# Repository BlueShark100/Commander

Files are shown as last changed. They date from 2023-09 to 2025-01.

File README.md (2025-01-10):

# Commander (code name Sirius 02)

Commander is essentially a little programable toy you can bring around to practice coding and have fun with if you not home with your usual projects. It's main purpose and code provides a menu that allows you to navigate through different OS tips and tricks along with keyboard shortcuts and their descriptions. Its like a little helper to make you a pro at navigating your computer faster and easier. I'm writing the code so respective to MacOS commands but feel free to interpret your own commands and edit the lists within the code to make your own version of the Commander. You can go as far as writing your own code for the board too! I'll provide pin assignments on an example code for pong on the project (after I finish the primary code). 

This project includes a builtin D-Pad, a 128*64 OLED display on an I2C connection, EEPROM with 4Kbytes, and side-fireing WS2812B LEDs to light up the case!

# Current status of the project (Second Version didnt work, Ordering test PCB)

### The Quick Version

- Completed reference animations
- Coding menu animation (Running into memory limits)
- **Test Board Arrived (Debugged one Issue! more to fix)**
- Case is hard to take apart

### Code

This is currently in development. I'm working to complete V1 still and if you happen to come across this repo feel free to help out. Right now I'm working on getting the menu animation completed on the display by using lists with coordinates for each element. As it goes through the loop it will "animate" the menu into creation. **Working on a solution to avoid overflowing the display buffer which may be the cause of unexpected behavior when running the animations.** Defined the animations as separate functions to avoid clutter at the top of the program where the primary functional code is.

Navigation through different folders and information is almost complete.

### Board

Originally I was planning on using the ATmega16U2 however I kept running into issues trying to find custom firmware to have it work as the primary MCU on the board. This MCU is commonly found on the Arduino Uno used as a USB to serial converter. I found a github repo called HoodLoader that aims to use this MCU as a microcontroller along side the primary MCU of the board (ATmega328p) however I honestly could never figure out how to get it to work with a standalone ATmega16U2. If anyone knows how to get the ATmega16U2 to run as a standalone MCU that would be the primary goal since that would allow for USB HID support

The new board will be using the CH340 USB to serial converter (using the RedBoard Qwuicc schematic for guidance since the data sheet is all in Chinese) and the ATmega328p. There will be no USB HID support but you should be able to program the board directly from a USB and the Arduino IDE. I'm adding an EEPROM module to store some of the byte arrays so that it doesn't take up program memory space. The specific EEPROM would be the Microchip Tech AT24C32D-SSHM-T, its got 32Kbits of storage (4Kbytes) and uses and I2C communication. The second version of the board includes output pins for the currently unused Arduino pins for expandability and a solder jumper for the Write Protect configuration on the EEPROM module.

Aside from the new board design (V2) there is a test board (V3) for me to try and debug problems with the circuit. I tried replicating the circuit from my schematic on a breadboard and it worked fine. However the circuit on the board itself seems to have a flaw that prevents me from flashing the bootloader onto the ATmega238p on the board itself using another arduino. I'm hoping that the layout of the test board will better help me find whats going wrong and how i could fix it for what will hopefully be the final version. 

If you are an hardware engineer and know how to do this please reach out. Everything I know about designing PCBs and circuits has been primarily self taught so I would love to learn form an expert. 

### Casing

I'm printing the casing out of a sparkling black PLA from Microcenter (Brand: inland). This filament gives a great effect with the sparkles giving some extra interest to the surface without being too distracting. It also slightly transparent when printed thin enough which allows the LEDs to shine through and illuminates the components inside while looking super cool! 

Working on a better mechanism to connect the bottom plate securely while still being able to take it out easily. 

### Prototyping

I'm prototyping the project on a breadboard while I go. That way I can continue working on the code while I wait for a working board to arrive. This section is mainly to put some images of what it looks like so far. I also have the images so there something cool to look at instead of a bunch of text in the README file. 

Here's a test of what the LEDs within the Case might look like. This is using the first version of the PCB and none of the components are within the case. Hopes are that when I do have the LEDs working and the components are inside you can see a faint outline of the components within the case.

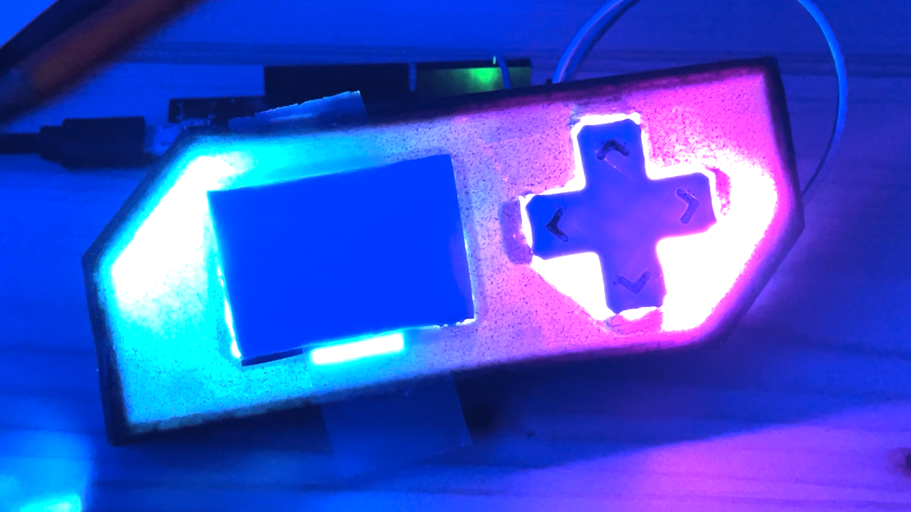
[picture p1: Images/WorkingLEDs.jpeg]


# How do I get one of my own?

**THIS PROJECT IS INCOMPLETE AT THE MOMENT. The code and files are not finalized and may not work as intended. Especially right now the project WILL NOT WORK.**

The commander project is a PCB at heart. You'll need to order the board from a manufacturer yourself. On top of the board you'll also have to order the components required for the circuit from lcsc. These components and the Gerber files for the PCB can be found under the PCB files. There will be a BOM that you can use to find the components quickly and easily in lcsc, the quantities will be defined for 1 board only but feel free to edit the quantities later if you want more boards or extra components.

Once the project is in working order I will write a guide for building this project from scratch.

# Extra tid bits

Heres the original sketch I drew when I first had the idea
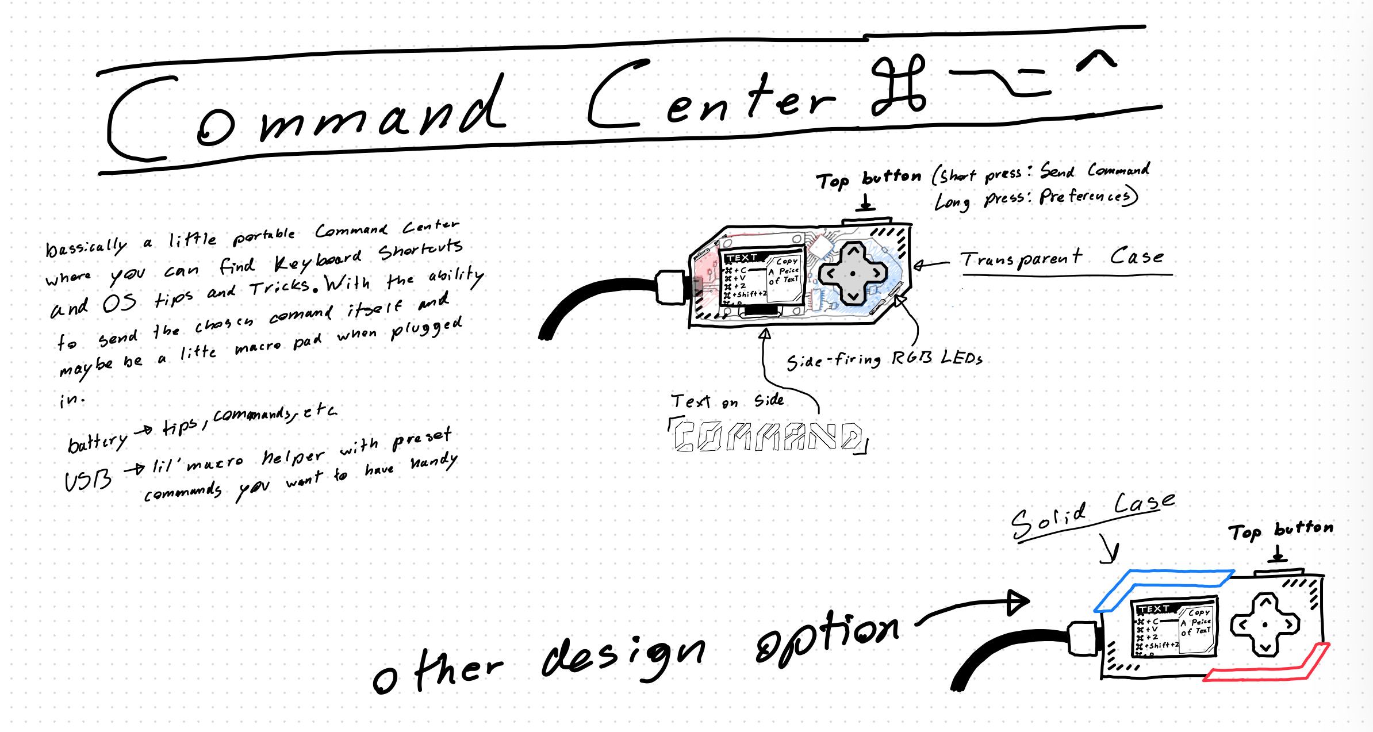
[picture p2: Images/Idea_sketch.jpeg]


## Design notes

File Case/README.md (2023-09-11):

# The Case
This case consists of two parts. The Case and the Case Bottom. The Case Bottom just 
squezes into the bottom of the case. Printed in sparkling black PLA from Microcenter

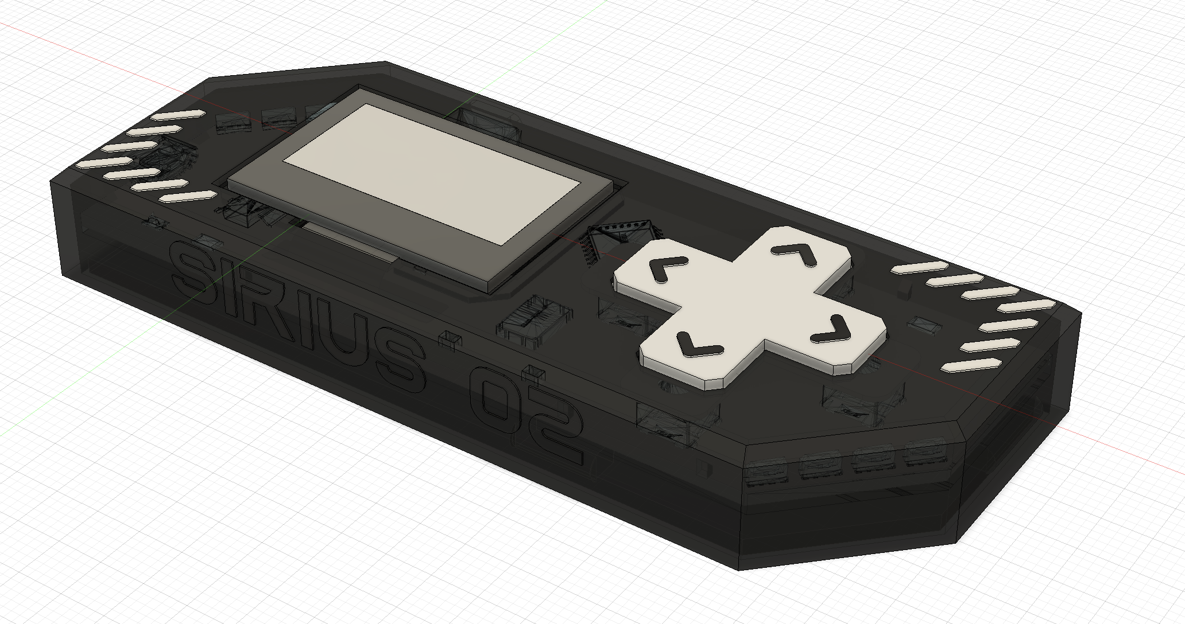
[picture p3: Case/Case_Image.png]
The case


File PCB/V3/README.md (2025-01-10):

# PCB V3

Version three is to try and debug the circuit used for V2. 

**Update!** I found an issue with the was I wired the 16MHz Crystal Oscilator I was using. I left the unused connections floating but I think I was suppost to ground them. I'm using a different one for now but I plan to make the original one work.

### issues

OLED Display is not working. Having trouble getting the CH340C to properly communicate with the MCU.

### Notes

- Sucsefully uploaded bootloater to MCU

- LEDs Working with MCU ✓

- Testing Button Reading soon

This PCB is designed for testing the circuit. There are lots of pads you can solder onto. *This one is mainly for me so I can see why the circuit for the last PCB didn't work.* I remade the circuit on a breadboard and it works so I'm real confused. I'll still include the same information as the last version that way it's known which component goes where and pin assignments for Arduino. The BOM is also the same as V2.

```
int Up_Button = 3;
int Down_Button = 4;
int Left_Button = 5;
int Right_Button = 6;
int LED_Data_Pin = 2;
//OLED(Address: 0x3C) and EEPROM(Waiting for board to arrive to confirm Address) are on the I2C bus on Pins A5(SCL) and A4(SDA)
```

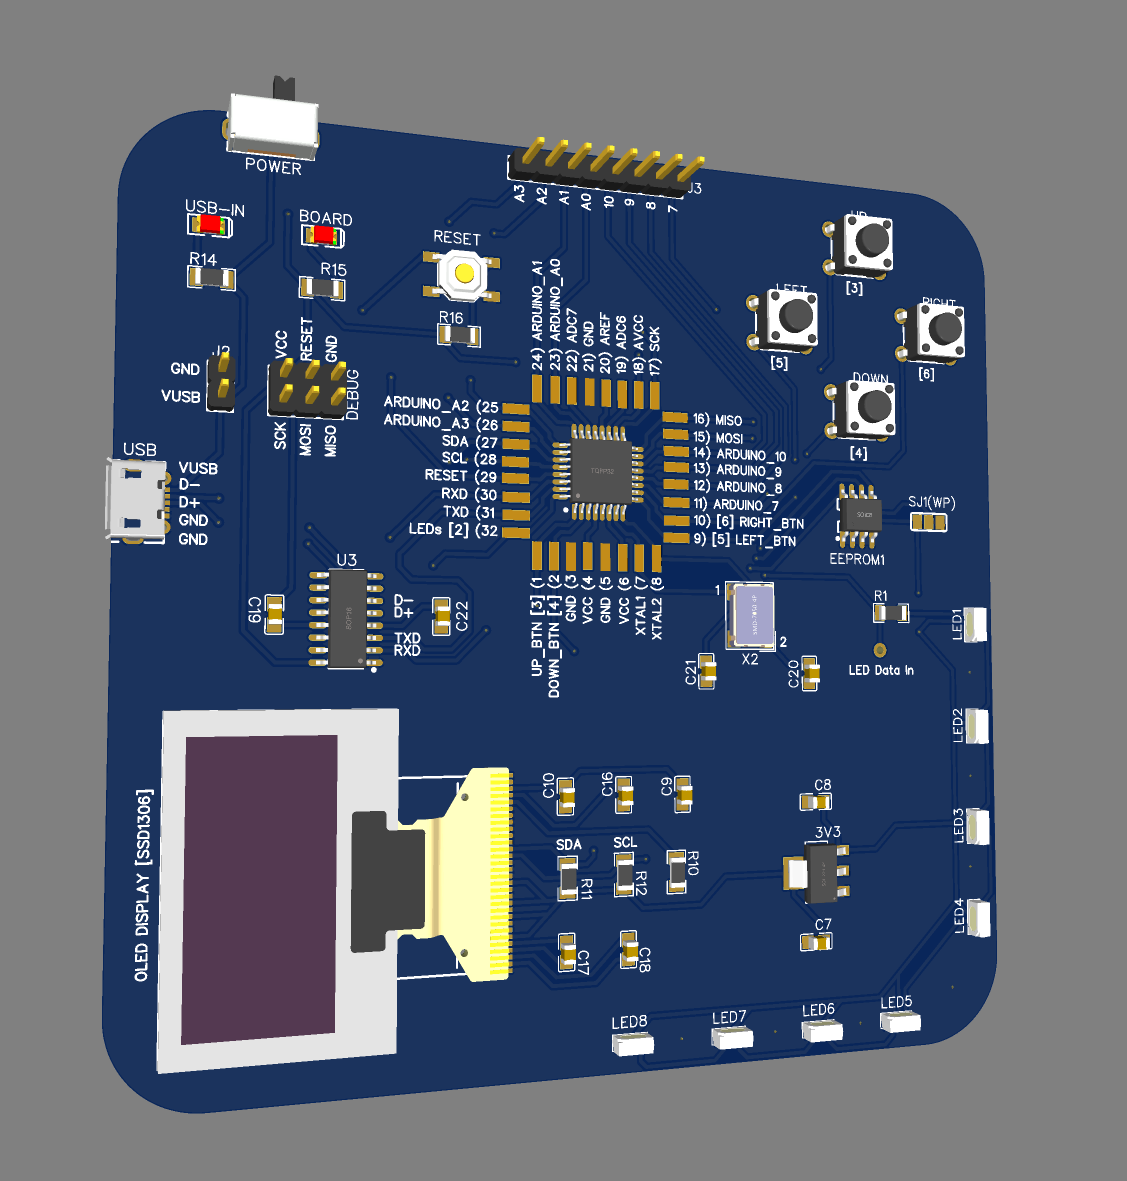
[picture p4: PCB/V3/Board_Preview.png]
BoardPreview

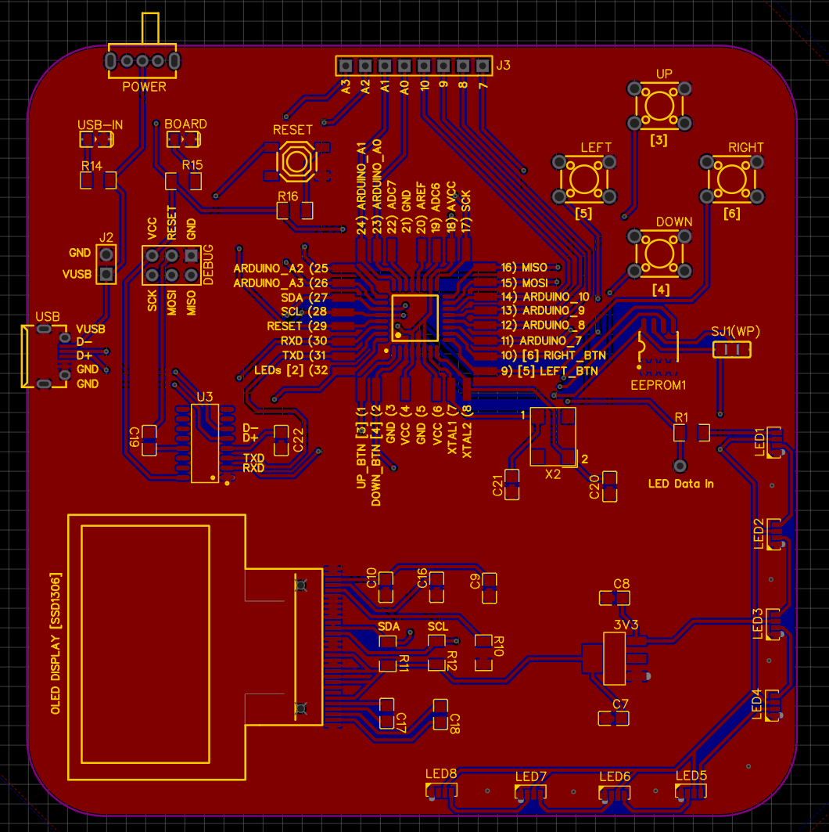
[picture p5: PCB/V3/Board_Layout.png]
BoardLayout


Component descriptions are as follows:

```arduino
C7 - 10uF capacitor
C8 - 10uF capacitor
C9 - 0.1uF capacitor
C10 - 10uF capacitor
C16 - 1uF capacitor
C17 - 1uF capacitor
C18 - 1uF capacitor
C19 - 100nF capacitor
C20 - 22pF capacitor
C21 - 22pF capacitor
C22 - 10nF capacitor

R10 - 1kΩ resistor
R11 - 1kΩ resistor
R12 - 1kΩ resistor
R13 - 330Ω resistor
R14 - 10kΩ resistor
R15 - 10kΩ resistor
R16 - 10kΩ resistor
```

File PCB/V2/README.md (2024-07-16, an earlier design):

# PCB V2
This is version two of the PCB, it will function using the ATmega328p with a USB to Serial converter so you can program it via the Arduino IDE

### issues
Trouble connecting to ATmega328p to load bootloader. I tried recreating the circuit on a breadboard and it worked there. There will be another version designed for testing the circuit on the board with test pads and labeling.

### Notes 
*Make sure to have the drivers for the CH340C USB to Serial converter installed for it to work properly.* Write/Protect solder jumper is connect to GND by default and allows normal write functions to the EEPROM module, when the right track is cut and the left pad is connected to the center pad via a solder bridge it will connect to VCC and block write functions to the EEPROM module. *Be Careful to ensure the right most and left most pads on the solder junction are not connected as to prevent a short circuit.* Integrated OLED module on the board is untested. Pin assignments for Arduino programming are as follows:
```
int Up_Button = 3;
int Down_Button = 4;
int Left_Button = 5;
int Right_Button = 6;
int LED_Data_Pin = 2;
//OLED(Address: 0x3C) and EEPROM(Waiting for board to arrive to confirm Address) are on the I2C bus on Pins A5(SCL) and A4(SDA)
```
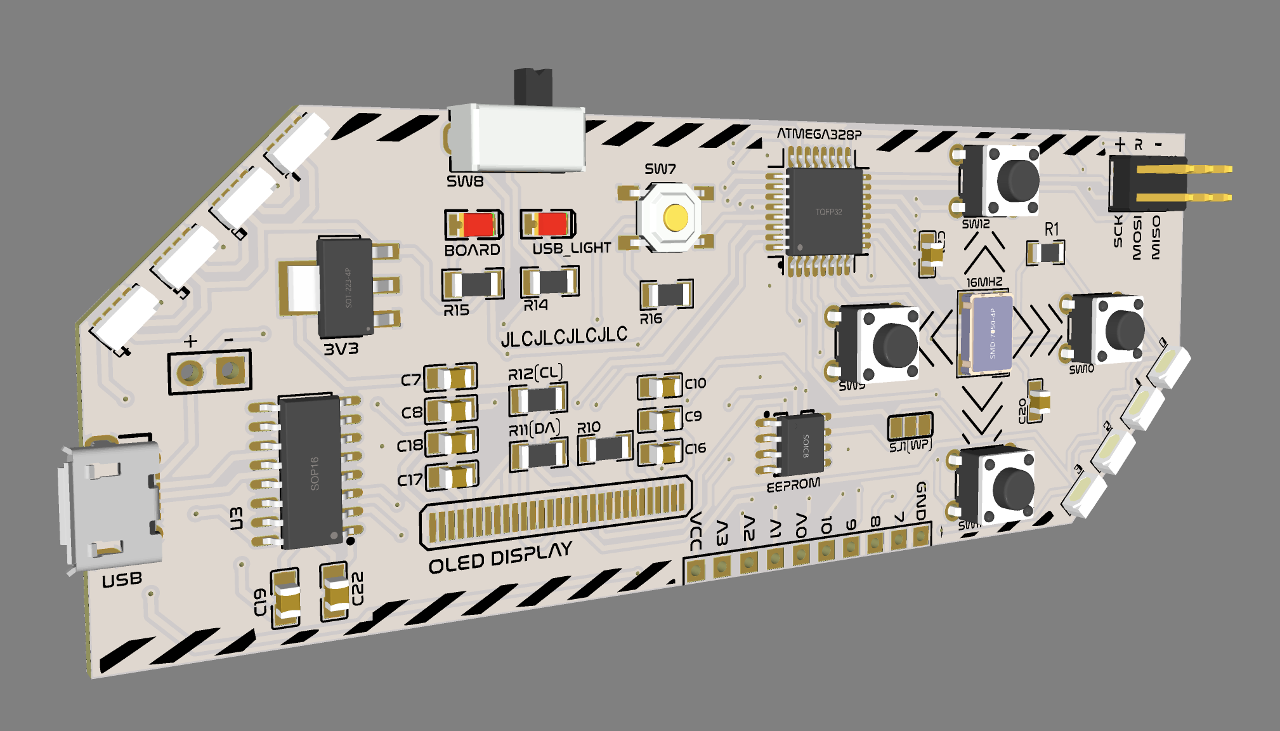
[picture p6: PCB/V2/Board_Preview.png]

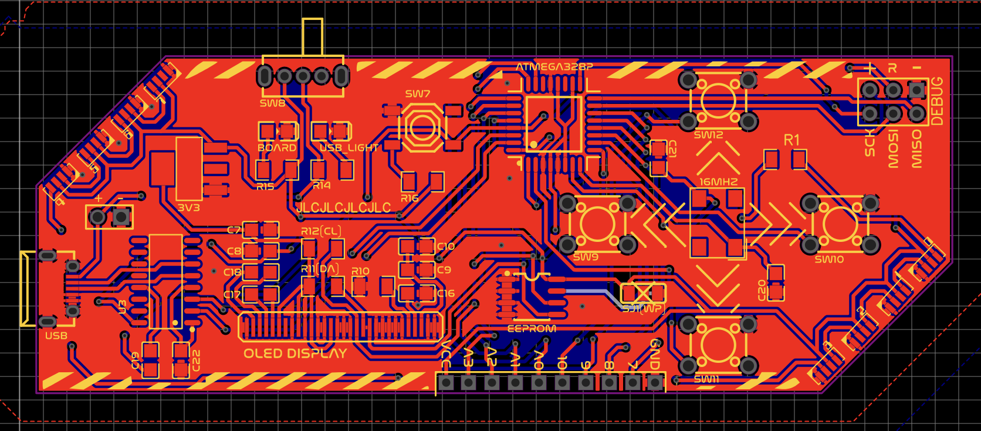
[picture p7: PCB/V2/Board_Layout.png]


Components descriptions are as follows:
```
C7 - 10uF capacitor
C8 - 10uF capacitor
C9 - 0.1uF capacitor
C10 - 10uF capacitor
C16 - 1uF capacitor
C17 - 1uF capacitor
C18 - 1uF capacitor
C19 - 100nF capacitor
C20 - 22pF capacitor
C21 - 22pF capacitor
C22 - 10nF capacitor

R10 - 1kΩ resistor
R11 - 1kΩ resistor
R12 - 1kΩ resistor
R13 - 330Ω resistor
R14 - 10kΩ resistor
R15 - 10kΩ resistor
R16 - 10kΩ resistor
```

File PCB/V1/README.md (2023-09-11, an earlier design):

# PCB V1
This is the first version of the PCB. It's setup to work with the ATmega16U2 and the BOM has quantities for myself so that I had extra parts when I ordered the components. 

### issues
Missing required resistors on data line for USB

### Notes 
Integrated OLED module on the board is untested. I dont have a reliable way to solder the ribbon cable from the OLED to the board for a secure connection yet. The left side of R8 connects to SDA of the OLED and the left side of R7 connects to SCL of the OLED.

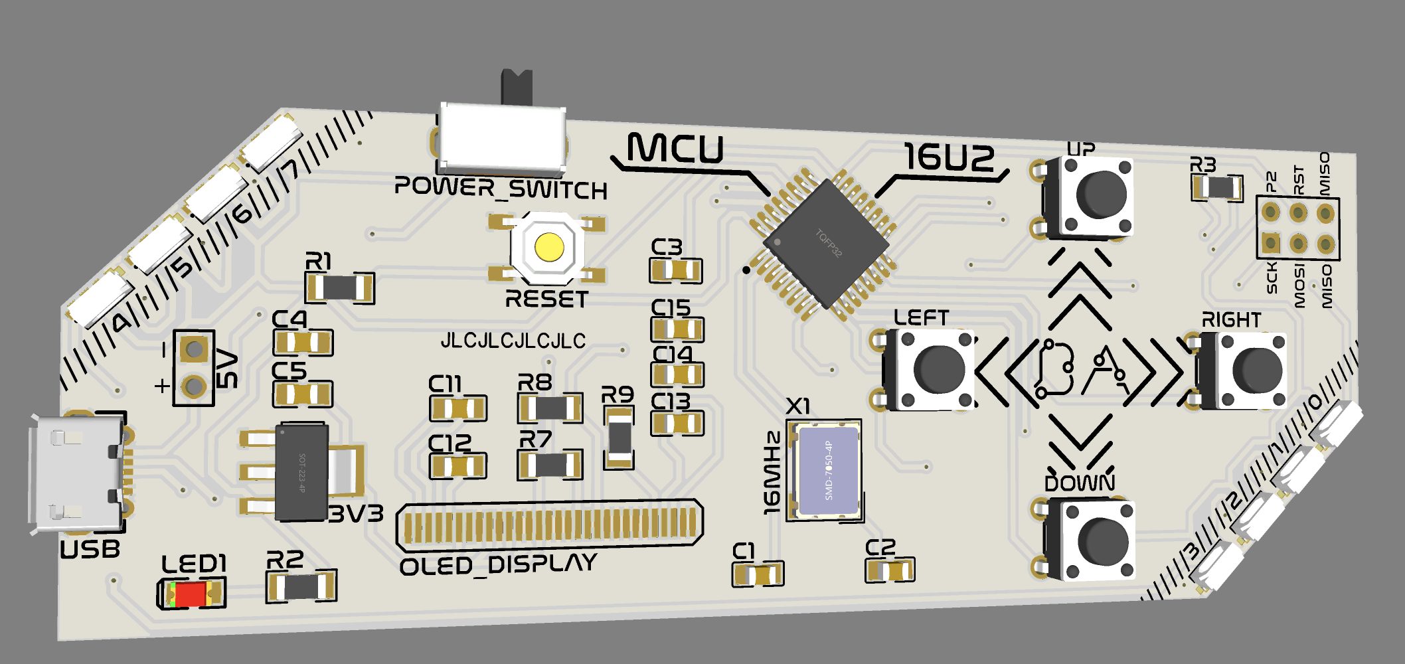
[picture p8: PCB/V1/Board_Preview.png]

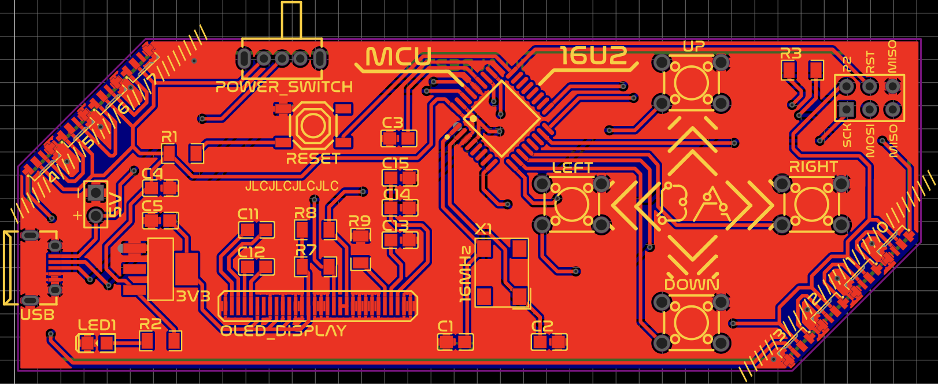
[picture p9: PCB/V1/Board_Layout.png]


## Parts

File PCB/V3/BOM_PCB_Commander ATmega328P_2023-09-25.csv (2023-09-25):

ID | Name | Designator | Footprint | Quantity | Manufacturer Part | Manufacturer | Supplier | Supplier Part | Price
1 | Arduino Pins | NONE |  | 1
2 | 0.1uF | C9 | C0805 | 1 | CT41G-0805-2X1-50V-0.1μF-M(N) | TORCH(火炬) | LCSC | C138340 | 0.007
3 | 1uF | C16,C17,C18 | C0805 | 3 | CC0805KKX7R9BB105 | YAGEO(国巨) | LCSC | C91185 | 0.017
4 | 100nF | C19 | C0805 | 1 | C0805B104K500NT | 火炬 | LCSC | C476766 | 0.004
5 | 10nF | C22 | C0805 | 1 | CC0805KRX7R9BB103 | YAGEO | LCSC | C83170 | 0.005
6 | AT24C32D-SSHM-T | EEPROM | SOIC-8_L5.0-W4.0-P1.27-LS6.0-BL | 1 | AT24C32D-SSHM-T | MICROCHIP(美国微芯) | LCSC | C60583 | 0.288
7 | SK6812SIDE-A-RVS | 7,6,5,4,3,2,1,0 | LED-SMD_4P-L4.0-W1.6-L | 8 | SK6812SIDE-A-RVS | 欧思科光电 | LCSC | C2890037 | 0.184
8 | JUMPER-PAD-3-2OF3_NC_BY_TRACE_LARGE | SJ1(WP) | PAD-JUMPER-3-2OF3_NC_BY_TRACE_YES_SILK_LARGE | 1
9 | TS-1187A-B-A-B | SW7 | SW-SMD_4P-L5.1-W5.1-P3.70-LS6.5-TL-2 | 1 | TS-1187A-B-A-B | XKB Connectivity(中国星坤) | LCSC | C318884 | 0.016
10 | SK12D07VG4 | POWER_SWITCH | SW-TH_SK12D07VG4 | 1 | SK12D07VG4 | SHOU HAN | LCSC | C393937 | 0.017
11 | ATMEGA328P-AU | ATMEGA328P | TQFP-32_L7.0-W7.0-P0.80-LS9.0-BL | 1 | ATMEGA328P-AU | MICROCHIP | LCSC | C14877 | 2.274
12 | CH340C | USB-SERIAL | SOP-16_L10.0-W3.9-P1.27-LS6.0-BL | 1 | CH340C | WCH | LCSC | C84681 | 0.476
13 | SC1117-3.3V | 3V3 | SOT-223_L6.5-W3.5-P2.30-LS7.0-BR | 1 | SC1117-3.3V | FM | LCSC | C173386 | 0.031
14 | 16MHz | 16MHZ | OSC-SMD_4P-L7.0-W5.0-BL | 1 | OCETDLJANF-16MHZ | TAITIEN(泰艺电子) | LCSC | C295103 | 0.635

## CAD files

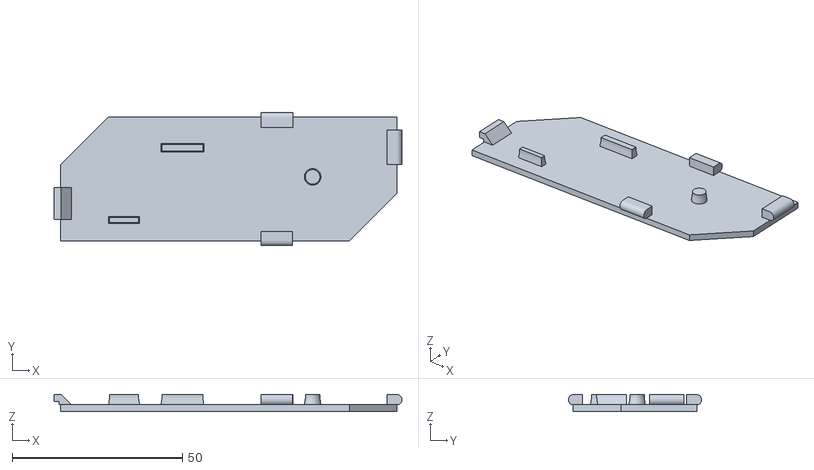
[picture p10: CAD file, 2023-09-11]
Case/Case Bottom.stl
102.2 x 39.1 x 5.00

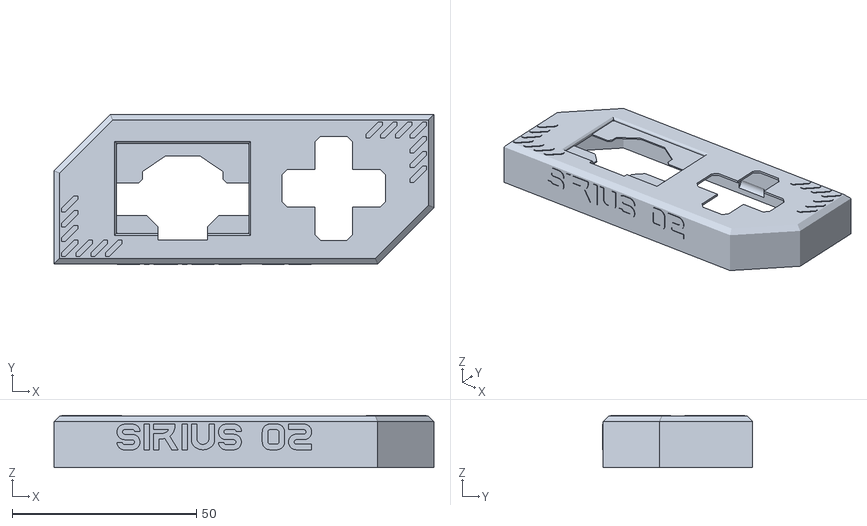
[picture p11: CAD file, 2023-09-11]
Case/Case.stl
103.1 x 40.8 x 14.2

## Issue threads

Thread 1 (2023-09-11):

Primary Code has unexpected behaviour when inlcuding lines to animate the top bar of the menu animation

BlueShark100, 2023-09-11:
When adding back in the lines to animate the top bar lines the arduino seems to refuse to run the project properly.
```
if (i > 7) {
    display.drawLine(0, 10, topbarLine[6][0], 10, WHITE);
    //display.drawLine(75, 5, topbarLine[7][1], 5, WHITE);
} else {
    //display.drawLine(0, 10, topbarLine[i][0], 10, WHITE);
    //display.drawLine(75, 5, topbarLine[i][1], 5, WHITE);
}
```
All variables and lists are defined properly and I don't seem to be running out of program memory. `i` also stays within the range of the list.

BlueShark100, 2023-10-12:
In the second version of the PCB I added an EEPROM module to store the byte arrays for the animations and the lists for the menu animation so hopefully it relieves some of the storage on the ATmega238p. Hopes are this issue is caused by an overflowing buffer or running out of flash storage while running the program. So by adding the permanent data in the EEPROM we can load only the parts we need into the buffer then flush them out to try and avoid overflowing it.

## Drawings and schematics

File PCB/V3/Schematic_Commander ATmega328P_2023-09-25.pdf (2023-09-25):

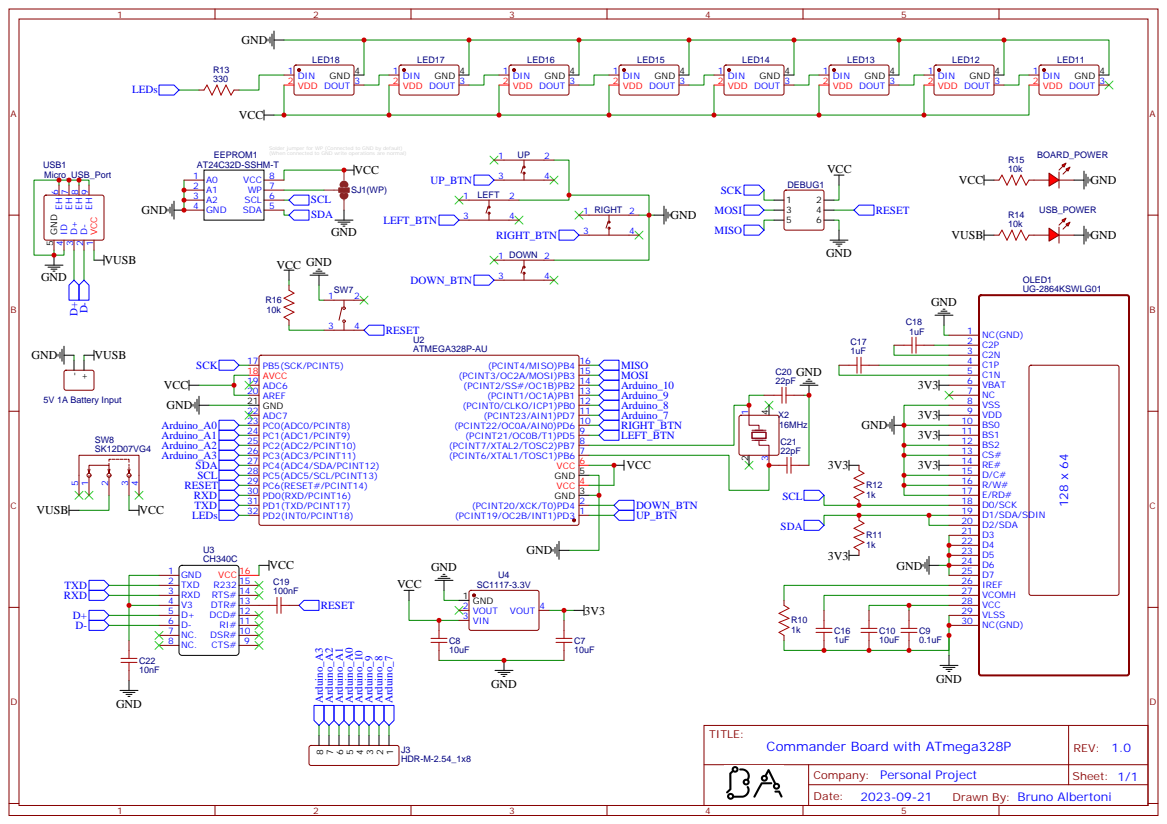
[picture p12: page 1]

Solder jumper for WP (Connected to GND by default)
(When connected to GND write operations are normal)
VCC 8
SCL 6

Drawn By: Bruno Albertoni

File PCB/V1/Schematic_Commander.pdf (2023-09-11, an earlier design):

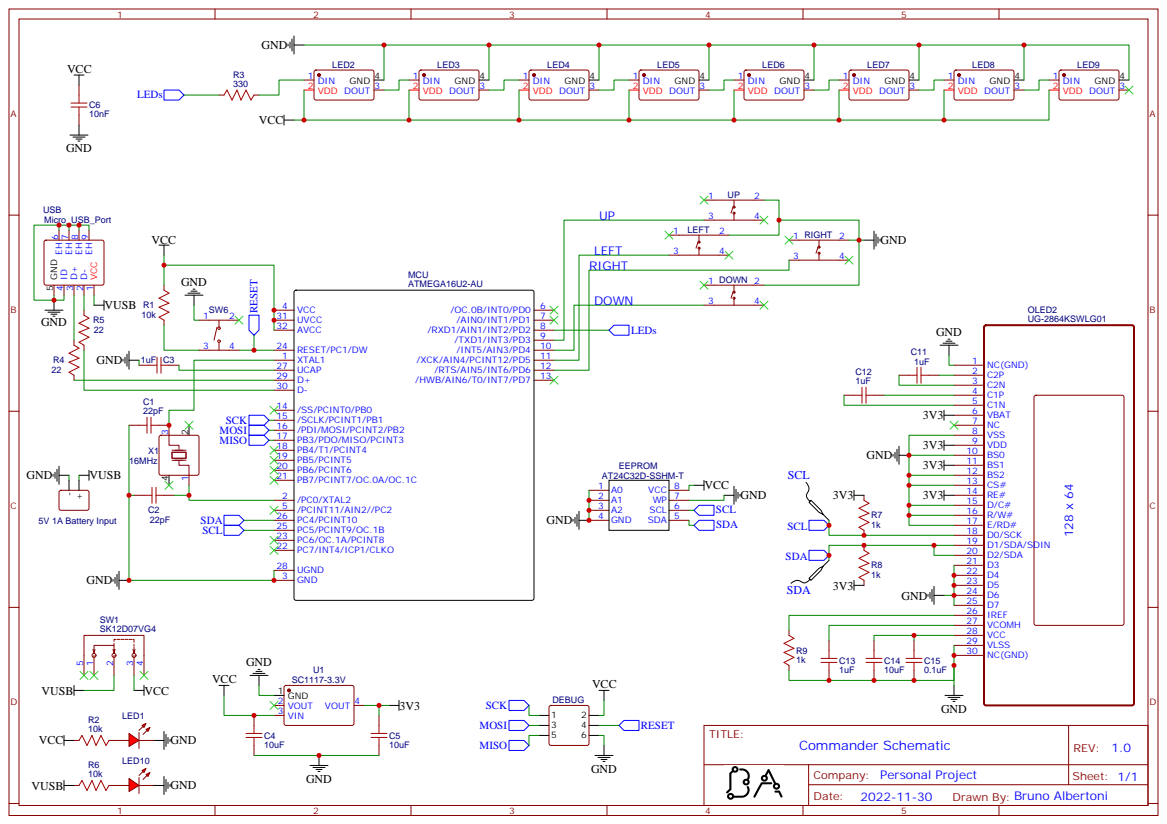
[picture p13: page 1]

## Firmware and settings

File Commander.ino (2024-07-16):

#include <Adafruit_GFX.h>
#include <Adafruit_SSD1306.h>
#include <Adafruit_NeoPixel.h>
#ifdef __AVR__
 #include <avr/power.h> // Required for 16 MHz Adafruit Trinket
#endif

const unsigned char ArrowIcon[] PROGMEM = {0x80, 0x40, 0x20, 0x40, 0x80};

int ArrowPos = 0;
int Select = 0;
int ArrowShift = 19;
int PrevArrowShift = 19;
int PrevSelect;
int PrevArrowPos;
int scroll = 0;

// Defining the pin the LEDs are connected to (D2)
#define LED_PIN    2

// Amount of LEDs
#define LED_COUNT  8

// Declare the LED strip object
Adafruit_NeoPixel strip(LED_COUNT, LED_PIN, NEO_GRB + NEO_KHZ800);
//define colors to use
uint32_t white = strip.Color(255, 255, 255);
uint32_t red = strip.Color(255, 0, 0);
uint32_t orange = strip.Color(255, 160, 0);
uint32_t yellow = strip.Color(255, 255, 0);
uint32_t green = strip.Color(0, 255, 0);
uint32_t cyan = strip.Color(0, 208, 255);
uint32_t blue = strip.Color(0, 70, 255);
uint32_t purple = strip.Color(170, 31, 255);
uint32_t pink = strip.Color(255, 0, 255);

//get these values from the EEPROM later but thet are setup with the proper checks so that this function is ready
bool MenuAnimation = false;
bool SplashAnimation = false;
uint32_t *TopColor = &cyan;
uint32_t *BottomColor = &pink;
int AutoScrollSpeed = 5; //lines per second

#define SCREEN_WIDTH 128 // OLED display width, in pixels
#define SCREEN_HEIGHT 64 // OLED display height, in pixels
#define OLED_RESET     -1 // Reset pin # (or -1 if sharing Arduino reset pin)
#define SCREEN_ADDRESS 0x3C ///< See datasheet for Address; 0x3D for 128x64, 0x3C for 128x32
Adafruit_SSD1306 display(SCREEN_WIDTH, SCREEN_HEIGHT, &Wire, OLED_RESET);

char *folders[7] = {"GENERAL","FINDER","TEXT","SYSTEM","POWER", "TIPS", "SETTINGS"}; //max characters that fit in a line is 9 so the arrow fits
char *folder_descriptions[7] = {"The Main Things","MacOS File Manager","Text Shortcuts","MacOS Global Commands","Restart, Shutdown, etc.", "Cool Stuff to Know", "Customise Your Device"};
char *General[6][2] = {{"cmd + C", "Copy"}, {"cmd + V", "Paste"}, {"cmd + T", "New tab"}, {"cmd + N", "new window"}, {"cmd + W", "Close tab/window"}, {"cmd + shift + W", "Close all tabs/windows"}};

char** CurrentFolder = folders;

void setup() {   

    //setup the pins for the Buttons
    pinMode(3, INPUT_PULLUP); //Up
    pinMode(4, INPUT_PULLUP); //Down
    pinMode(5, INPUT_PULLUP); //Left
    pinMode(6, INPUT_PULLUP); //Right

    Serial.begin(9600);

    //start the display object
    // SSD1306_SWITCHCAPVCC = generate display voltage from 3.3V internally
    display.begin(SSD1306_SWITCHCAPVCC, SCREEN_ADDRESS);

    //setup the LED strip
    strip.begin();
    strip.show();
    strip.setBrightness(255);

    //clear the display before we start so it doesnt show anything goofy like the arduino library splash screen (that i think i might be legally reqiured to do if i'm using the library and selling the code for profit)
    display.clearDisplay();
    display.display();
    delay(200);

    //once the splash screen is done turn off all the LEDs and clear the display. 
    strip.clear();
    strip.show();
    display.clearDisplay();
    display.display();

    splash_Animation();
    menu_Animation();

    //end of splashscreen
    delay(100);
}

void loop() { //all of this isnt part of the actual code yet and will be changed

  int press_start;
  display.setCursor(0,0);
  display.setTextColor(SSD1306_WHITE);
  if (digitalRead(3) == HIGH & digitalRead(4) == HIGH & digitalRead(5) == HIGH & digitalRead(6) == HIGH) {
    press_start = millis();
    PrevArrowPos = ArrowPos;
    PrevSelect = Select;
    PrevArrowShift = ArrowShift;
  } //once a button is pressed start timing it to later detect long presses (will be used to scroll faster through the menus)

  if (int(millis() - press_start) > 500) {
      //display.setCursor(10, 0);
  } //if its been pressed for over 500 miliseconds indent the text to show that its been detected

  if (digitalRead(3) == LOW) { //display the corresponding direction with the button that has been pressed.
      //display.println("UP");
      Select--;
      ArrowPos--;
  } else if (digitalRead(4) == LOW) {
      //display.println("DOWN");
      Select++;
      ArrowPos++;
  } else if (digitalRead(5) == LOW) {
      //display.println("LEFT");
  } else if (digitalRead(6) == LOW) {
      //display.println("RIGHT");
  }

  if ((ArrowPos < 0) && (Select > -1)) { //move the arrow up only if within range
    scroll_Items("UP");
    ArrowPos = 0;
    PrevSelect = Select;
    ArrowShift = 19;
  } else if ((ArrowPos > 3) && (Select <= ((sizeof(folders)/2)) - 1)) { //move the arrow down only if within range
    scroll_Items("DOWN");
    ArrowPos = 3;
    PrevSelect = Select;
    ArrowShift = 23;
  } else if ((Select > ((sizeof(folders)/2)) - 1) or (Select <= -1)) { //make sure we dont go out of range by resseting the values to thier original state
    ArrowPos = PrevArrowPos;
    Select = PrevSelect;
  }

  display.fillRect((String(folders[PrevSelect]).length()*6) + 9, PrevArrowShift + (PrevArrowPos * 11), 3, 5, BLACK);//get rid of the previous arrow by filling in the space
  display.drawBitmap((String(folders[Select]).length()*6) + 9, ArrowShift + (ArrowPos * 11), ArrowIcon, 3, 5, WHITE); //draw the new arrow at the correct location based of the name of the folder and staying in line with the vertical location of the folder.

  display.fillRect(74, 15, 51, 47, BLACK); //clear the area to draw the description of the folders

  for (int i = 0; i <= String(folder_descriptions[Select]).length(); i = i + 8) { //Loop by the amount of line needed to display the description within the space. i represents the chracter number so we increase by 8 becasue thats how many fit in a line
    if (i == 0) {display.setCursor(77, 15);} else {display.setCursor(74, 15 + (i));} //if its the first one indent the first line to accomodate for the beveled corner
    
    if (String(String(folder_descriptions[Select]).substring(i, i + 8).charAt(0)) == " ") { //if the second line starts with a space then get rid of it and increase i by one to make up for the missing character.
      display.println(String(folder_descriptions[Select]).substring(i + 1, i + 9));
      i++;
    } else {
      display.println(String(folder_descriptions[Select]).substring(i, i + 8)); //print the line from the current character number and the next 8 characters to fill the space
    }
  }
  while (digitalRead(3) == LOW or digitalRead(4) == LOW or digitalRead(5) == LOW or digitalRead(6) == LOW) {} //while we are pressing a button make sure to do nothing so it doesnt fun all the functions like 50 times per press.

  display.display(); //display changes
}

void scroll_Items(String UpOrDown) {
  int textPlace = 18; //where the whole thing is placed. starts at 18 cause thats the default but might change if we are scrolling down to display the last value at the very bottom
  int startDraw = 0;

  if (UpOrDown == "UP") {
    scroll--;
  } else if ((UpOrDown == "DOWN") && !(scroll < 0)) {
    scroll++;
    textPlace = 22; //moves the folders just a little down to show the bottom name
    startDraw = -1;
  };

  display.fillRect(0, 11, 70, 55, BLACK); //clear the text area in order to drew the new (moved) folder names 

  for (int i = startDraw; i < 5; i++) {
    display.drawLine(0, (textPlace - 1) + (i * 11), 0, (textPlace + 7) + (i * 11), WHITE);
    display.setCursor(4, textPlace + (i * 11));
    display.println(CurrentFolder[i + scroll]);
  }
  display.drawLine(0, 11, 70, 11, BLACK); // lil spacer between the text clipping into the top bar

  display.display();
}

void splash_Animation() {
  //Byte array for the splash screen animation
  const unsigned char splash2[] PROGMEM = {0x00, 0x00, 0x00, 0x00, 0x00, 0x00, 0x00, 0x00, 0x00, 0x00, 0x00, 0x00, 0x00, 0x00, 0x00, 0x00, 0x00, 0x00, 0x00, 0x00, 0x00, 0x00, 0x00, 0x00, 0x00, 0x00, 0x00, 0x00, 0x00, 0x00, 0x00, 0x00, 0x00, 0x00, 0x00, 0x00, 0x00, 0x00, 0x00, 0x00, 0x00, 0x00, 0x00, 0x00, 0x00, 0x00, 0x00, 0x00, 0x00, 0x00, 0x00, 0x00, 0x00, 0x00, 0x00, 0x00, 0x00, 0x00, 0x00, 0x00, 0x00, 0x00, 0x00, 0x00, 0x00, 0x00, 0x00, 0x00, 0x00, 0x00, 0x00, 0x00, 0x00, 0x00, 0x00, 0x00, 0x00, 0x00, 0x00, 0x00, 0x00, 0x00, 0x00, 0x00, 0x00, 0x00, 0x00, 0x00, 0x00, 0x00, 0x00, 0x00, 0x00, 0x00, 0x00, 0x00, 0x00, 0x00, 0x00, 0x00, 0x00, 0x00, 0x00, 0x00, 0x00, 0xf0, 0x00, 0x00, 0x00, 0x00, 0x00, 0x00, 0x00, 0x00, 0x00, 0x00, 0x00, 0x00, 0x00, 0x00, 0x00, 0x00, 0x00, 0x00, 0x00, 0x00, 0x00, 0x00, 0x00, 0x00, 0x00, 0x00, 0x00, 0x00, 0x00, 0x00, 0x00, 0x00, 0x00, 0x00, 0x00, 0x00, 0x00, 0x00, 0x00, 0x00, 0x00, 0x00, 0x00, 0x00, 0x00, 0x00, 0x00, 0x00, 0x00, 0x00, 0x00, 0x00, 0x00, 0x00, 0x00, 0x00, 0x00, 0x00, 0x00, 0x00, 0x00, 0x00, 0x00, 0x00, 0x00, 0x00, 0x00, 0x00, 0x00, 0x00, 0x00, 0x00, 0x00, 0x00, 0x00, 0x00, 0x00, 0x00, 0x00, 0x00, 0x00, 0x00, 0x00, 0x00, 0x00, 0x00, 0x00, 0x00, 0x00, 0x00, 0x00, 0x00, 0x00, 0x00, 0x00, 0x00, 0x00, 0x00, 0x00, 0x00, 0x00, 0x00, 0x00, 0x00, 0x00, 0x00, 0x00, 0x00, 0x00, 0x00, 0x00, 0x00, 0x00, 0x00, 0x00, 0x00, 0x00, 0x00, 0x00, 0x00, 0x00, 0x00, 0x00, 0x00, 0x00, 0x00, 0x00, 0x00, 0x00, 0x00, 0x00, 0x00, 0x00, 0x00, 0x00, 0x00, 0x00, 0x00, 0x00, 0x00, 0x00, 0x00, 0x00, 0x00, 0x00, 0x00, 0x00, 0x00, 0x00, 0x00, 0x00, 0x00, 0x00, 0x00, 0x00, 0x00, 0x00, 0x00, 0x00, 0x00, 0x00, 0x00, 0x00, 0x00, 0x00, 0x00, 0x00, 0x00, 0x00, 0x00, 0x00, 0x00, 0x00, 0x00, 0x00, 0x00, 0x00, 0x00, 0x00, 0x00, 0x00, 0x00, 0x00, 0x00, 0x00, 0x00, 0x00, 0x00, 0x00, 0x00, 0x00, 0x00, 0x00, 0x00, 0x00, 0x00, 0x00, 0x00, 0x00, 0x00, 0x00, 0x00, 0x00, 0x00, 0x00, 0x00, 0x00, 0x00, 0x00, 0x00, 0x00, 0x00, 0x00, 0x00, 0x00, 0x00, 0x00, 0x00, 0x00, 0x00, 0x00, 0x00, 0x00, 0x00, 0x00, 0x00, 0x00, 0x00, 0x00, 0x00, 0x00, 0x00, 0x00, 0x00, 0x00, 0x00, 0x00, 0x00, 0x00};
  const unsigned char splash3[] PROGMEM = {0x00, 0x00, 0x00, 0x00, 0x00, 0x00, 0x00, 0x00, 0x00, 0x00, 0x00, 0x00, 0x00, 0x00, 0x00, 0x00, 0x00, 0x00, 0x00, 0x00, 0x00, 0x00, 0x00, 0x00, 0x00, 0x00, 0x00, 0x00, 0x00, 0x00, 0x00, 0x00, 0x00, 0x00, 0x00, 0x00, 0x00, 0x00, 0x00, 0x00, 0x00, 0x00, 0x00, 0x00, 0x00, 0x00, 0x00, 0x00, 0x00, 0x00, 0x00, 0x00, 0x00, 0x00, 0x00, 0x00, 0x00, 0x00, 0x00, 0x00, 0xfc, 0x00, 0x00, 0x00, 0x00, 0x00, 0x00, 0x00, 0x00, 0x00, 0x00, 0x00, 0x00, 0x00, 0x00, 0x08, 0x00, 0x00, 0x00, 0x00, 0x00, 0x00, 0x00, 0x00, 0x00, 0x00, 0x00, 0x00, 0x00, 0x00, 0x08, 0x00, 0x00, 0x00, 0x00, 0x00, 0x00, 0x00, 0x00, 0x00, 0x00, 0x00, 0x00, 0x00, 0x00, 0x10, 0x00, 0x00, 0x00, 0x00, 0x00, 0x00, 0x00, 0x00, 0x00, 0x00, 0x00, 0x00, 0x00, 0x00, 0x10, 0x00, 0x00, 0x00, 0x00, 0x00, 0x00, 0x00, 0x00, 0x00, 0x00, 0x00, 0x00, 0x00, 0x00, 0x20, 0x00, 0x00, 0x00, 0x00, 0x00, 0x00, 0x00, 0x00, 0x00, 0x00, 0x00, 0x00, 0x00, 0x00, 0x20, 0x00, 0x00, 0x00, 0x00, 0x00, 0x00, 0x00, 0x00, 0x00, 0x00, 0x00, 0x00, 0x00, 0x00, 0xc0, 0x00, 0x00, 0x00, 0x00, 0x00, 0x00, 0x00, 0x00, 0x00, 0x00, 0x00, 0x00, 0x00, 0x00, 0x00, 0x00, 0x00, 0x00, 0x00, 0x00, 0x00, 0x00, 0x00, 0x00, 0x00, 0x00, 0x00, 0x00, 0x00, 0x00, 0x00, 0x00, 0x00, 0x00, 0x00, 0x00, 0x00, 0x00, 0x00, 0x00, 0x00, 0x00, 0x00, 0x00, 0x00, 0x00, 0x00, 0x00, 0x00, 0x00, 0x00, 0x00, 0x00, 0x00, 0x00, 0x00, 0x00, 0x00, 0x00, 0x00, 0x00, 0x00, 0x00, 0x00, 0x00, 0x00, 0x00, 0x00, 0x00, 0x00, 0x00, 0x00, 0x00, 0x00, 0x00, 0x00, 0x00, 0x00, 0x00, 0x00, 0x00, 0x00, 0x00, 0x00, 0x00, 0x00, 0x00, 0x00, 0x00, 0x00, 0x00, 0x00, 0x00, 0x00, 0x00, 0x00, 0x00, 0x00, 0x00, 0x00, 0x00, 0x00, 0x00, 0x00, 0x00, 0x00, 0x00, 0x00, 0x00, 0x00, 0x00, 0x00, 0x00, 0x00, 0x00, 0x00, 0x00, 0x00, 0x00, 0x00, 0x00, 0x00, 0x00, 0x00, 0x00, 0x00, 0x00, 0x00, 0x00, 0x00, 0x00, 0x00, 0x00, 0x00, 0x00, 0x00, 0x00, 0x00, 0x00, 0x00, 0x00, 0x00, 0x00, 0x00, 0x00, 0x00, 0x00, 0x00, 0x00, 0x00, 0x00, 0x00, 0x00, 0x00, 0x00, 0x00, 0x00, 0x00, 0x00, 0x00, 0x00, 0x00, 0x00, 0x00, 0x00, 0x00, 0x00, 0x00, 0x00, 0x00, 0x00, 0x00, 0x00, 0x00, 0x00, 0x00, 0x00, 0x00, 0x00};
  const unsigned char splash4[] PROGMEM = {0x00, 0x00, 0x00, 0x00, 0x00, 0x00, 0x00, 0x00, 0x00, 0x00, 0x00, 0x00, 0x00, 0x00, 0x00, 0x00, 0x00, 0x00, 0x00, 0x00, 0x00, 0x00, 0x00, 0x00, 0x00, 0x00, 0x00, 0x00, 0x00, 0x00, 0xfe, 0x00, 0x00, 0x00, 0x00, 0x00, 0x00, 0x00, 0x00, 0x00, 0x00, 0x00, 0x00, 0x00, 0x00, 0x04, 0x00, 0x00, 0x00, 0x00, 0x00, 0x00, 0x00, 0x00, 0x00, 0x00, 0x00, 0x00, 0x00, 0x00, 0x04, 0x00, 0x00, 0x00, 0x00, 0x00, 0x00, 0x00, 0x00, 0x00, 0x00, 0x00, 0x00, 0x00, 0x00, 0x08, 0x00, 0x00, 0x00, 0x00, 0x00, 0x00, 0x00, 0x00, 0x00, 0x00, 0x00, 0x00, 0x00, 0x00, 0x08, 0x00, 0x00, 0x00, 0x00, 0x00, 0x00, 0x00, 0x00, 0x00, 0x00, 0x00, 0x00, 0x00, 0x00, 0x10, 0x00, 0x00, 0x00, 0x00, 0x00, 0x00, 0x00, 0x00, 0x00, 0x00, 0x00, 0x00, 0x00, 0x00, 0x10, 0x00, 0x00, 0x00, 0x00, 0x00, 0x00, 0x00, 0x00, 0x00, 0x00, 0x00, 0x00, 0x00, 0x00, 0x20, 0x00, 0x00, 0x00, 0x00, 0x00, 0x00, 0x00, 0x00, 0x00, 0x00, 0x00, 0x00, 0x00, 0x00, 0x20, 0x00, 0x00, 0x00, 0x00, 0x00, 0x00, 0x00, 0x00, 0x00, 0x00, 0x00, 0x00, 0x00, 0x00, 0x40, 0x00, 0x00, 0x00, 0x00, 0x00, 0x00, 0x00, 0x00, 0x00, 0x00, 0x00, 0x00, 0x00, 0x00, 0x40, 0x00, 0x00, 0x00, 0x00, 0x00, 0x00, 0x00, 0x00, 0x00, 0x00, 0x00, 0x00, 0x00, 0x00, 0x80, 0x00, 0x00, 0x00, 0x00, 0x00, 0x00, 0x00, 0x00, 0x00, 0x00, 0x00, 0x00, 0x00, 0x00, 0x00, 0x00, 0x00, 0x00, 0x00, 0x00, 0x00, 0x00, 0x00, 0x00, 0x00, 0x00, 0x00, 0x00, 0x00, 0x00, 0x00, 0x00, 0x00, 0x00, 0x00, 0x00, 0x00, 0x00, 0x00, 0x00, 0x00, 0x00, 0x00, 0x00, 0x00, 0x00, 0x00, 0x00, 0x00, 0x00, 0x00, 0x00, 0x00, 0x00, 0x00, 0x00, 0x00, 0x00, 0x00, 0x00, 0x00, 0x00, 0x00, 0x00, 0x00, 0x00, 0x00, 0x00, 0x00, 0x00, 0x00, 0x00, 0x00, 0x00, 0x00, 0x00, 0x00, 0x00, 0x00, 0x00, 0x00, 0x00, 0x00, 0x00, 0x00, 0x00, 0x00, 0x00, 0x00, 0x00, 0x00, 0x00, 0x00, 0x00, 0x00, 0x00, 0x00, 0x00, 0x00, 0x00, 0x00, 0x00, 0x00, 0x00, 0x00, 0x00, 0x00, 0x00, 0x00, 0x00, 0x00, 0x00, 0x00, 0x00, 0x00, 0x00, 0x00, 0x00, 0x00, 0x00, 0x00, 0x00, 0x00, 0x00, 0x00, 0x00, 0x00, 0x00, 0x00, 0x00, 0x00, 0x00, 0x00, 0x00, 0x00, 0x00, 0x00, 0x00, 0x00, 0x00, 0x00, 0x00, 0x00, 0x00, 0x00, 0x00, 0x00, 0x00, 0x00};
  const unsigned char splash5[] PROGMEM = {0x00, 0x00, 0x00, 0x00, 0x00, 0x00, 0x00, 0x00, 0x00, 0x00, 0x00, 0x00, 0x00, 0x00, 0x00, 0xfe, 0x00, 0x00, 0x00, 0x00, 0x00, 0x00, 0x00, 0x00, 0x00, 0x00, 0x00, 0x00, 0x00, 0x00, 0x02, 0x00, 0x00, 0x00, 0x00, 0x00, 0x00, 0x00, 0x00, 0x00, 0x00, 0x00, 0x00, 0x00, 0x00, 0x04, 0x00, 0x00, 0x00, 0x00, 0x00, 0x00, 0x00, 0x00, 0x00, 0x00, 0x00, 0x00, 0x00, 0x00, 0x04, 0x00, 0x00, 0x00, 0x00, 0x00, 0x00, 0x00, 0x00, 0x00, 0x00, 0x00, 0x00, 0x00, 0x00, 0x08, 0x00, 0x00, 0x00, 0x00, 0x00, 0x00, 0x00, 0x00, 0x00, 0x00, 0x00, 0x00, 0x00, 0x00, 0x08, 0x00, 0x00, 0x00, 0x00, 0x00, 0x00, 0x00, 0x00, 0x00, 0x00, 0x00, 0x00, 0x00, 0x00, 0x10, 0x00, 0x00, 0x00, 0x00, 0x00, 0x00, 0x00, 0x00, 0x00, 0x00, 0x00, 0x00, 0x00, 0x00, 0x10, 0x00, 0x00, 0x00, 0x00, 0x00, 0x00, 0x00, 0x00, 0x00, 0x00, 0x00, 0x00, 0x00, 0x00, 0x20, 0x00, 0x00, 0x00, 0x00, 0x00, 0x00, 0x00, 0x00, 0x00, 0x00, 0x00, 0x00, 0x00, 0x00, 0x20, 0x00, 0x00, 0x00, 0x00, 0x00, 0x00, 0x00, 0x00, 0x00, 0x00, 0x00, 0x00, 0x00, 0x00, 0x40, 0x00, 0x00, 0x00, 0x00, 0x00, 0x00, 0x00, 0x00, 0x00, 0x00, 0x00, 0x00, 0x00, 0x00, 0x40, 0x00, 0x00, 0x00, 0x00, 0x00, 0x00, 0x00, 0x00, 0x00, 0x00, 0x00, 0x00, 0x00, 0x00, 0x80, 0x00, 0x00, 0x00, 0x00, 0x00, 0x00, 0x00, 0x00, 0x00, 0x00, 0x00, 0x00, 0x00, 0x00, 0x80, 0x00, 0x00, 0x00, 0x00, 0x00, 0x00, 0x00, 0x00, 0x00, 0x00, 0x00, 0x00, 0x00, 0x00, 0x00, 0x00, 0x00, 0x00, 0x00, 0x00, 0x00, 0x00, 0x00, 0x00, 0x00, 0x00, 0x00, 0x00, 0x00, 0x00, 0x00, 0x00, 0x00, 0x00, 0x00, 0x00, 0x00, 0x00, 0x00, 0x00, 0x00, 0x00, 0x00, 0x00, 0x00, 0x00, 0x00, 0x00, 0x00, 0x00, 0x00, 0x00, 0x00, 0x00, 0x00, 0x00, 0x00, 0x00, 0x00, 0x00, 0x00, 0x00, 0x00, 0x00, 0x00, 0x00, 0x00, 0x00, 0x00, 0x00, 0x00, 0x00, 0x00, 0x00, 0x00, 0x00, 0x00, 0x00, 0x00, 0x00, 0x00, 0x00, 0x00, 0x00, 0x00, 0x00, 0x00, 0x00, 0x00, 0x00, 0x00, 0x00, 0x00, 0x00, 0x00, 0x00, 0x00, 0x00, 0x00, 0x00, 0x00, 0x00, 0x00, 0x00, 0x00, 0x00, 0x00, 0x00, 0x00, 0x00, 0x00, 0x00, 0x00, 0x00, 0x00, 0x00, 0x00, 0x00, 0x00, 0x00, 0x00, 0x00, 0x00, 0x00, 0x00, 0x00, 0x00, 0x00, 0x00, 0x00, 0x00, 0x00, 0x00, 0x00};
  const unsigned char splash6[] PROGMEM = {0xfe, 0x00, 0x00, 0x00, 0x00, 0x00, 0x00, 0x00, 0x00, 0x00, 0x00, 0x00, 0x00, 0x00, 0x00, 0x02, 0x00, 0x00, 0x00, 0x00, 0x00, 0x00, 0x00, 0x00, 0x00, 0x00, 0x00, 0x00, 0x00, 0x00, 0x02, 0x00, 0x00, 0x00, 0x00, 0x00, 0x00, 0x00, 0x00, 0x00, 0x00, 0x00, 0x00, 0x00, 0x00, 0x04, 0x00, 0x00, 0x00, 0x00, 0x00, 0x00, 0x00, 0x00, 0x00, 0x00, 0x00, 0x00, 0x00, 0x00, 0x04, 0x00, 0x00, 0x00, 0x00, 0x00, 0x00, 0x00, 0x00, 0x00, 0x00, 0x00, 0x00, 0x00, 0x00, 0x08, 0x00, 0x00, 0x00, 0x00, 0x00, 0x00, 0x00, 0x00, 0x00, 0x00, 0x00, 0x00, 0x00, 0x00, 0x08, 0x00, 0x00, 0x00, 0x00, 0x00, 0x00, 0x00, 0x00, 0x00, 0x00, 0x00, 0x00, 0x00, 0x00, 0x10, 0x00, 0x00, 0x00, 0x00, 0x00, 0x00, 0x00, 0x00, 0x00, 0x00, 0x00, 0x00, 0x00, 0x00, 0x10, 0x00, 0x00, 0x00, 0x00, 0x00, 0x00, 0x00, 0x00, 0x00, 0x00, 0x00, 0x00, 0x00, 0x00, 0x20, 0x00, 0x00, 0x00, 0x00, 0x00, 0x00, 0x00, 0x00, 0x00, 0x00, 0x00, 0x00, 0x00, 0x00, 0x20, 0x00, 0x00, 0x00, 0x00, 0x00, 0x00, 0x00, 0x00, 0x00, 0x00, 0x00, 0x00, 0x00, 0x00, 0x40, 0x00, 0x00, 0x00, 0x00, 0x00, 0x00, 0x00, 0x00, 0x00, 0x00, 0x00, 0x00, 0x00, 0x00, 0x40, 0x00, 0x00, 0x00, 0x00, 0x00, 0x00, 0x00, 0x00, 0x00, 0x00, 0x00, 0x00, 0x00, 0x00, 0x80, 0x00, 0x00, 0x00, 0x00, 0x00, 0x00, 0x00, 0x00, 0x00, 0x00, 0x00, 0x00, 0x00, 0x00, 0x80, 0x00, 0x00, 0x00, 0x00, 0x00, 0x00, 0x00, 0x00, 0x00, 0x00, 0x00, 0x00, 0x00, 0x00, 0x00, 0x00, 0x00, 0x00, 0x00, 0x00, 0x00, 0x00, 0x00, 0x00, 0x00, 0x00, 0x00, 0x00, 0x00, 0x00, 0x00, 0x00, 0x00, 0x00, 0x00, 0x00, 0x00, 0x00, 0x00, 0x00, 0x00, 0x00, 0x00, 0x00, 0x00, 0x00, 0x00, 0x00, 0x00, 0x00, 0x00, 0x00, 0x00, 0x00, 0x00, 0x00, 0x00, 0x00, 0x00, 0x00, 0x00, 0x00, 0x00, 0x00, 0x00, 0x00, 0x00, 0x00, 0x00, 0x00, 0x00, 0x00, 0x00, 0x00, 0x00, 0x00, 0x00, 0x00, 0x00, 0x00, 0x00, 0x00, 0x00, 0x00, 0x00, 0x00, 0x00, 0x00, 0x00, 0x00, 0x00, 0x00, 0x00, 0x00, 0x00, 0x00, 0x00, 0x00, 0x00, 0x00, 0x00, 0x00, 0x00, 0x00, 0x00, 0x00, 0x00, 0x00, 0x00, 0x00, 0x00, 0x00, 0x00, 0x00, 0x00, 0x00, 0x00, 0x00, 0x00, 0x00, 0x00, 0x00, 0x00, 0x00, 0x00, 0x00, 0x00, 0x00, 0x00, 0x00, 0x00, 0x00, 0x00, 0x00};
  const unsigned char splash7[] PROGMEM = {0xff, 0xfc, 0x00, 0x00, 0x00, 0x00, 0x00, 0x00, 0x00, 0x00, 0x00, 0x00, 0x00, 0x00, 0x00, 0x82, 0x04, 0x00, 0x00, 0x00, 0x00, 0x00, 0x00, 0x00, 0x00, 0x00, 0x00, 0x00, 0x00, 0x00, 0x82, 0x04, 0x00, 0x00, 0x00, 0x00, 0x00, 0x00, 0x00, 0x00, 0x00, 0x00, 0x00, 0x00, 0x00, 0x84, 0x08, 0x00, 0x00, 0x00, 0x00, 0x00, 0x00, 0x00, 0x00, 0x00, 0x00, 0x00, 0x00, 0x00, 0x84, 0x08, 0x00, 0x00, 0x00, 0x00, 0x00, 0x00, 0x00, 0x00, 0x00, 0x00, 0x00, 0x00, 0x00, 0x88, 0x10, 0x00, 0x00, 0x00, 0x00, 0x00, 0x00, 0x00, 0x00, 0x00, 0x00, 0x00, 0x00, 0x00, 0x88, 0x10, 0x00, 0x00, 0x00, 0x00, 0x00, 0x00, 0x00, 0x00, 0x00, 0x00, 0x00, 0x00, 0x00, 0x90, 0x20, 0x00, 0x00, 0x00, 0x00, 0x00, 0x00, 0x00, 0x00, 0x00, 0x00, 0x00, 0x00, 0x00, 0x90, 0x20, 0x00, 0x00, 0x00, 0x00, 0x00, 0x00, 0x00, 0x00, 0x00, 0x00, 0x00, 0x00, 0x00, 0xa0, 0x40, 0x00, 0x00, 0x00, 0x00, 0x00, 0x00, 0x00, 0x00, 0x00, 0x00, 0x00, 0x00, 0x00, 0xa0, 0x40, 0x00, 0x00, 0x00, 0x00, 0x00, 0x00, 0x00, 0x00, 0x00, 0x00, 0x00, 0x00, 0x00, 0xc0, 0x80, 0x00, 0x00, 0x00, 0x00, 0x00, 0x00, 0x00, 0x00, 0x00, 0x00, 0x00, 0x00, 0x00, 0xc0, 0x80, 0x00, 0x00, 0x00, 0x00, 0x00, 0x00, 0x00, 0x00, 0x00, 0x00, 0x00, 0x00, 0x00, 0x81, 0x00, 0x00, 0x00, 0x00, 0x00, 0x00, 0x00, 0x00, 0x00, 0x00, 0x00, 0x00, 0x00, 0x00, 0x81, 0x00, 0x00, 0x00, 0x00, 0x00, 0x00, 0x00, 0x00, 0x00, 0x00, 0x00, 0x00, 0x00, 0x00, 0xfe, 0x00, 0x00, 0x00, 0x00, 0x00, 0x00, 0x00, 0x00, 0x00, 0x00, 0x00, 0x00, 0x00, 0x00, 0x00, 0x00, 0x00, 0x00, 0x00, 0x00, 0x00, 0x00, 0x00, 0x00, 0x00, 0x00, 0x00, 0x00, 0x00, 0x00, 0x00, 0x00, 0x00, 0x00, 0x00, 0x00, 0x00, 0x00, 0x00, 0x00, 0x00, 0x00, 0x00, 0x00, 0x00, 0x00, 0x00, 0x00, 0x00, 0x00, 0x00, 0x00, 0x00, 0x00, 0x00, 0x00, 0x00, 0x00, 0x00, 0x00, 0x00, 0x00, 0x00, 0x00, 0x00, 0x00, 0x00, 0x00, 0x00, 0x00, 0x00, 0x00, 0x00, 0x00, 0x00, 0x00, 0x00, 0x00, 0x00, 0x00, 0x00, 0x00, 0x00, 0x00, 0x00, 0x00, 0x00, 0x00, 0x00, 0x00, 0x00, 0x00, 0x00, 0x00, 0x00, 0x00, 0x00, 0x00, 0x00, 0x00, 0x00, 0x00, 0x00, 0x00, 0x00, 0x00, 0x00, 0x00, 0x00, 0x00, 0x00, 0x00, 0x00, 0x00, 0x00, 0x00, 0x00, 0x00, 0x00};
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

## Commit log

2023-09-11 Add all the files I have so far
    [BOM Commander.csv]
2023-09-11 Add current Arduino code
2023-09-11 Add to PCB V1
2023-09-11 Add the Case files
    [Case Bottom.stl, Case.stl]
2023-09-25 Created the Second PCB And Updated README.md
    [BOM Commander.csv, BOM_PCB_Commander ATmega328P_2023-09-25.csv]
2023-09-27 Update PCB Gerber
2024-07-16 Add Test PCB
    Added a V3 folder for a test PCB to try and debug the circuit better. Also (hopefully) added .DS_Store to .gitignore
    [BOM_PCB_Commander ATmega328P_2023-09-25.csv]
2025-01-10 Update Info
    New bug on the board found. Progress is continuing again!
